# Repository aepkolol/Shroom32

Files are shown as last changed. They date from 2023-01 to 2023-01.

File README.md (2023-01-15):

# Shroom32
mycology monitoring and automation

This is the start of a project to monitor and automate a "fuiting" tub for growing mushrooms. 

I'll give some basic building instructions, but at the moment this is a very rough project I started a few days ago from parts I already had on hand. I included the fusion360 file I was buildig this in for others to edit to suit their needs if needed. Some details may be missing/lacking. Feel free to open an issue and I can clarify anything. This was also my first time using the water level sensor, it came in a kit of other parts years ago. My initial tests show it sucks. I don't feel like fixing that right now, so feel free to omit it, the code should run fine without, it'll just constantly show 0% water. 

Right now the water chamber is filled via a mountain dew bottle with a hole drilled into the cap where the water tube goes. I'll eventually make something nicer. The idea is to have water gravity fed via that tube and it should stop at the right water level as long as the tube is secured properly inside. 

The webapp is also pretty rough at the moment while I add features to it. Its designed with Bootstrap5 and uses websockets to talk to the "server" to get sensor data. The data is graphed using charts.js. 

The humidity is controlled by an ultrasonic mister bought off Amazon and a 5010 radial fan partially disasembled. (I may have stole this idea from the Voron 3D printer team). The monitoring is done mainly by a BME688 sensor. 
Right now the main webpage displays the humidity, temperature, pressure and gas as a KOhm value. 
It is possible to use the AI gas detection of the BME688 sensor, however I'm not entirely sure how to go about that. If someone smarter than me wants to figure that out, please do. Maybe a graph of CO2 in the fruiting chamber? Detection of unwanted bacteria growth? I dunno! It's over my head at the moment. 

## TODO:
- Store x amount of sensor values serverside to save graph data between browser refreshes
- Edit and save batch info/dates.
- Save min/max values to the SPIFFs 
- Add neopixel lighting to the inside of the fruiting chamber with adjustable time cycles
- Some way to notify user of an alarm state (temp/humidity/water, etc)
- Ability to have more than one, and link the data to a central node
- Design a gravity fed water supply to the humidifier. 
- Possibly slight redesigns to use an ESP32 cam module for real time viewing inside the fruiting chamber. 

## Parts required:
- The contents of the "STL" folder 3D printed in the material of your choice (PETG prefered, a soft TPE for the gaskets)
- a 24v 5010 radial fan (TBD: Add link to exact one)
- a ultrasonic mister (TBD: Add link to exact one)
- BME688
- Water sensor (TBD: Add link to exact one)
- ESP32
- Relay module
- Buck converter
- Potentiometer (if you want fan control) <- Not the best way to do this, but how I'm doing it for now.
- 4x M3 heatset inserts
- Countersunk M3 and M2.5 screws
- A few feet of 6.5mm OD silicone tube. I had some on hand from some random Amazon DC pumps. 

## Pinouts 
You can wire this how you choose to, the pins are defined in the start of main.cpp. This is how it is default. 
- BME688
  - SDA - GPIO_21
  - SCL - GPIO_22
  - GND - GND
  - VCC - 3.3v/5v depending on sensor
  
- Relay 
  - COM - 12v in
  - NO - V+ to Ultrasonic mister and potentometer
  - NC - Not connected 
  - VCC - 5v from buck converter
  - GND - out neg from buck
  - TRIG - GPIO_16
  
- Water sensor 
  - VCC - GPIO_27
  - GND - GND of ESP32 or buck converter 
  - SENSE - GPIO_34
  
- Fan
  - V+ - Output of potentiometer
  - V- - neg of 12v input (I soldered to the IN side of the buck)
  
## Printing:
- Gaskets - Use a soft TPE material. If you don't have the ability to print TPE, you can probably use hot glue or RTV or something. You may need to edit the CAD files to adjust the fit of the bottom lid since it takes into account the gaskets. 
- Everything else - PETG is probably best. You do you though. 

## Building:
See the guide folder for basic building instructions

## Issues:
- 24v radial fan is too powerful IMO. My quick fix was to add a potentiometer to limit the voltage of the fan. This works, but isn't ideal. Since the fan isn't on 100% of the time, it should be fine. If the fan draws too much power or shorts out, it could burn out the pot. 
- Water level sensor sucks. 
- I haven't designed a mount for the BME688 sensor, mine is just hanging by the wires while I worked on the rest of the stuff.

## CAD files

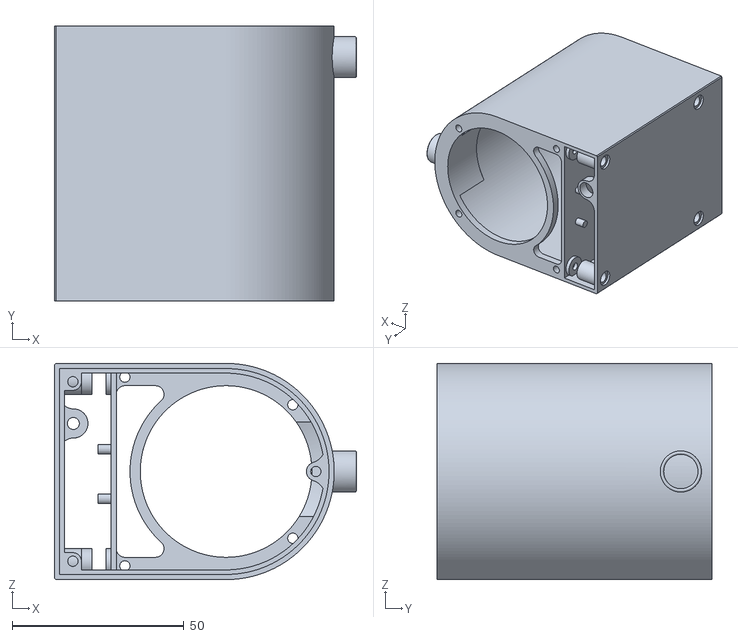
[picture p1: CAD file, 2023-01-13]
STL/Main Body.stl
88.0 x 80.0 x 63.0

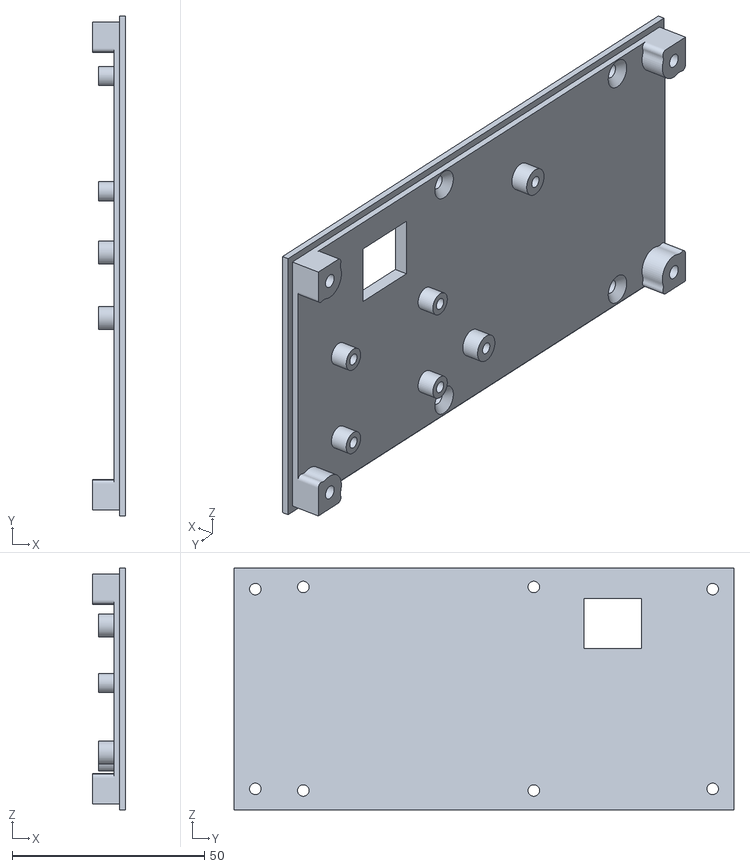
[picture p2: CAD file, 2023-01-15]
STL/Outside box.stl
8.50 x 130.1 x 63.0

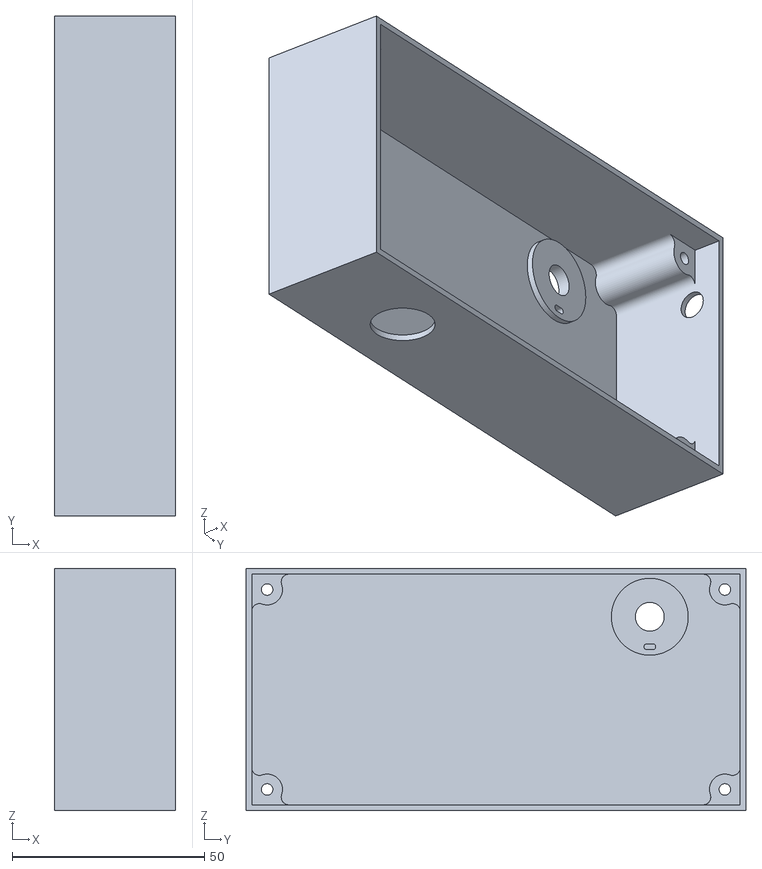
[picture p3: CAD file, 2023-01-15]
STL/Outside cover.stl
31.5 x 130.1 x 63.0

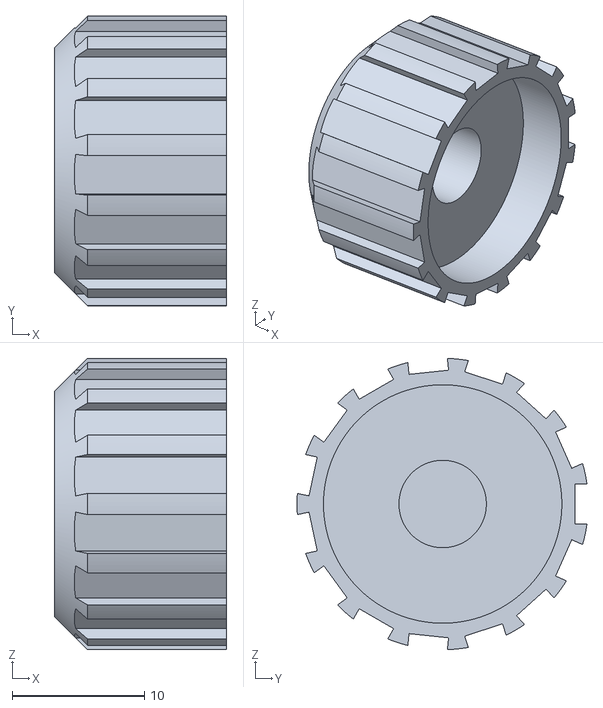
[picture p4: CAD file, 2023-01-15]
STL/Knob.stl
13.0 x 21.9 x 22.0

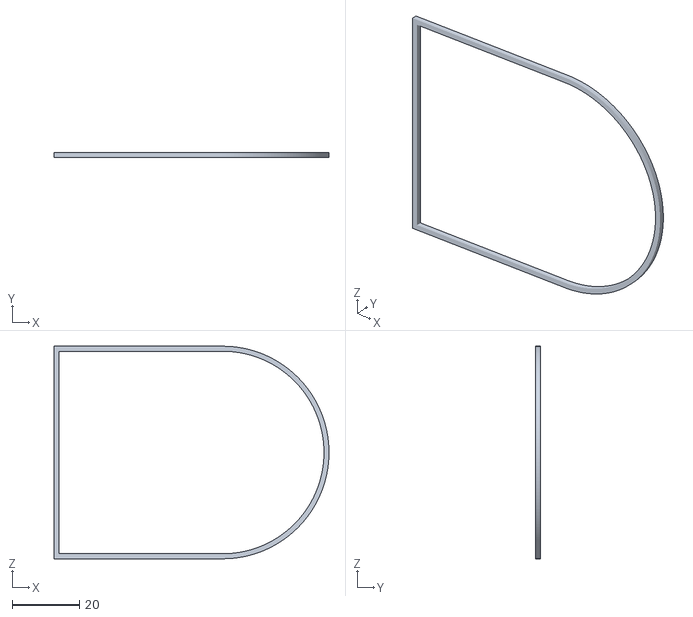
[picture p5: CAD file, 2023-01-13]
STL/Gasket.stl
81.5 x 1.40 x 63.0

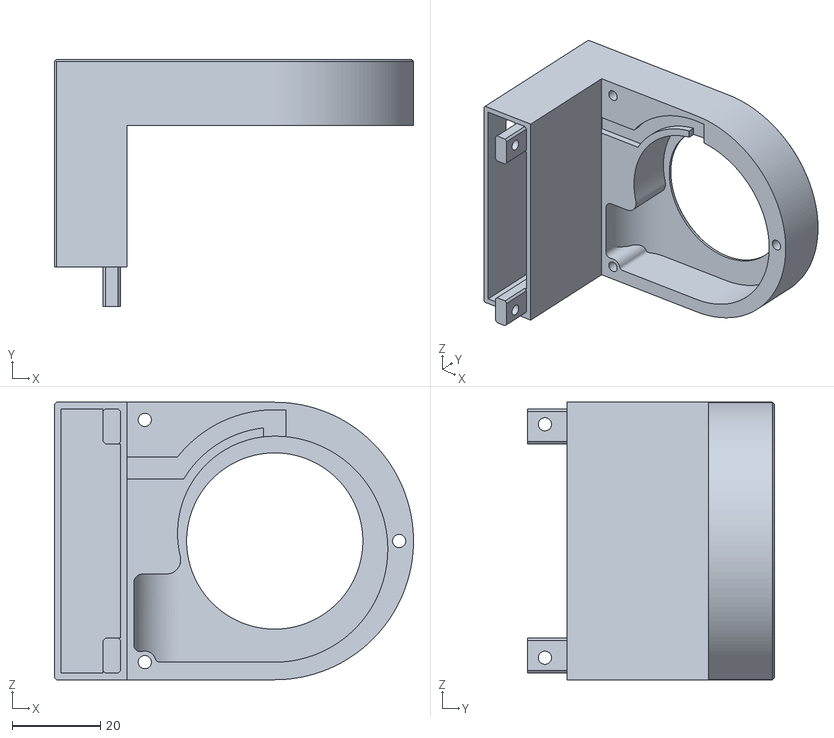
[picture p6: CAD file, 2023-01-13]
STL/Fan shroud.stl
81.5 x 56.0 x 63.0

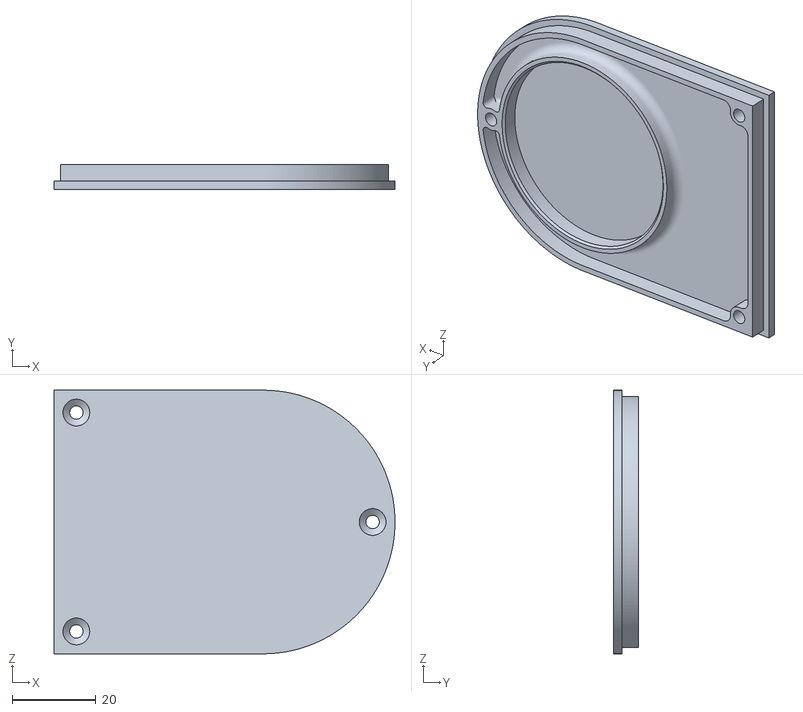
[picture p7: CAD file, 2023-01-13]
STL/Bottom.stl
81.5 x 6.00 x 63.0

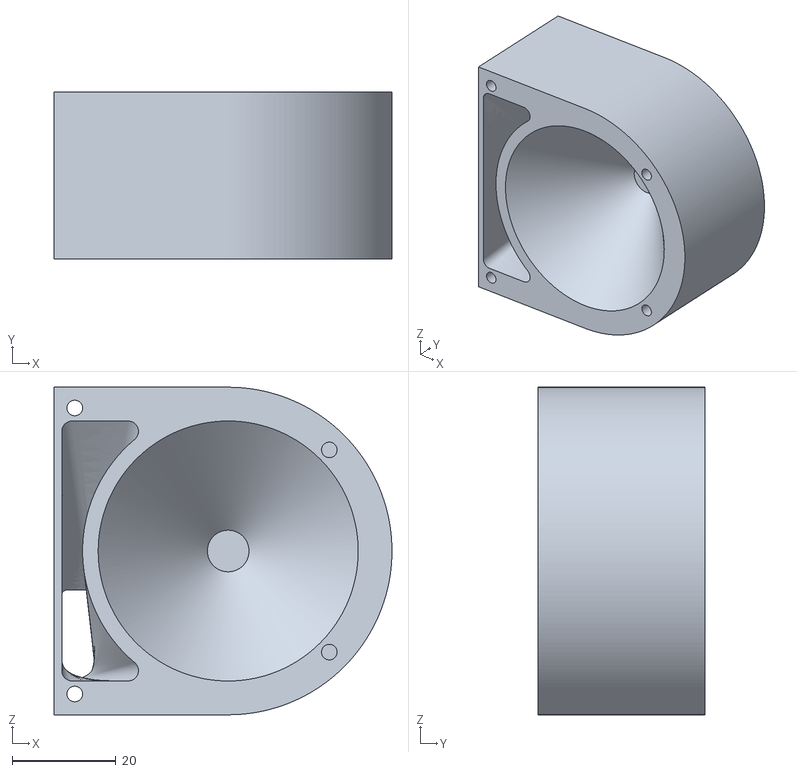
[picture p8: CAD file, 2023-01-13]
STL/Drip catch.stl
65.0 x 32.1 x 63.0

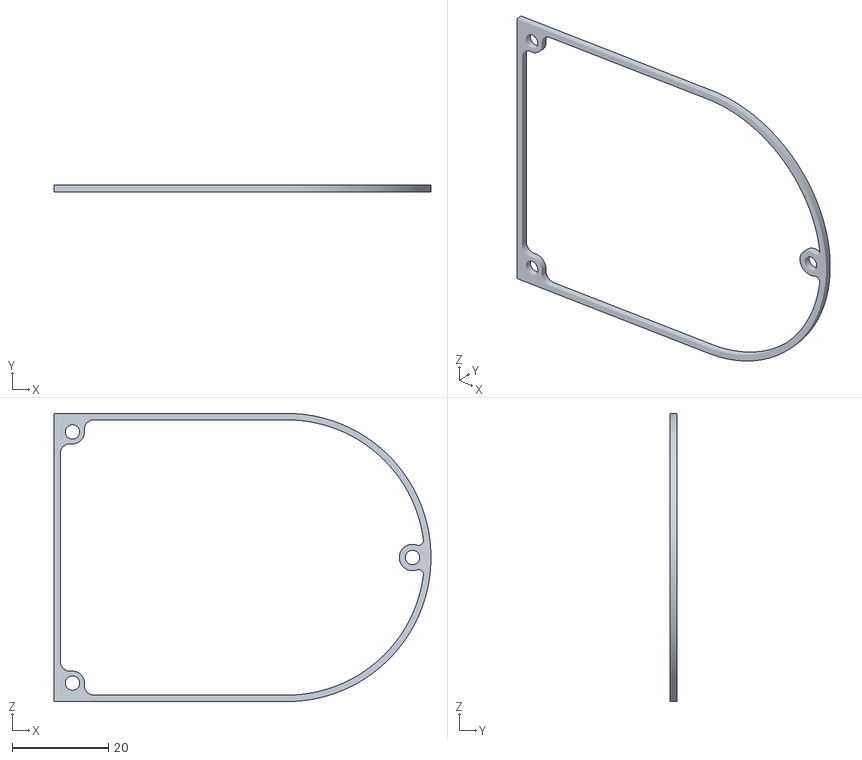
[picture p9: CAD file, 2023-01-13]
STL/Inner Gasket.stl
78.5 x 1.40 x 60.0

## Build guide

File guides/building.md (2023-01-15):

## The fan shroud 

This is the part that actually blows the humidified air out of the main body. To start, you'll need a 5015 radial fan. Remove the top casing from the fan by breaking off the tabs. You'll also need to remove the "ears". I used wire cutters to snip the casing beside the ears and bent them off. You can be pretty messy with this, it's going inside another enclosure. It just needs to fit, and the fan blades need to spin freely. 

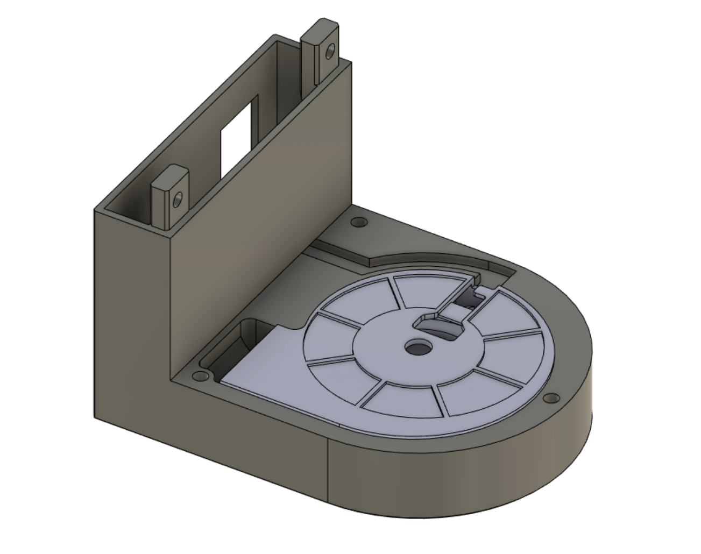
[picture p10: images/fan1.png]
guide image


Now place this modified fan inside the fanshroud.stl you printed off. Fit the wiring of the fan in the wire path and through the hole at the end of the path. 

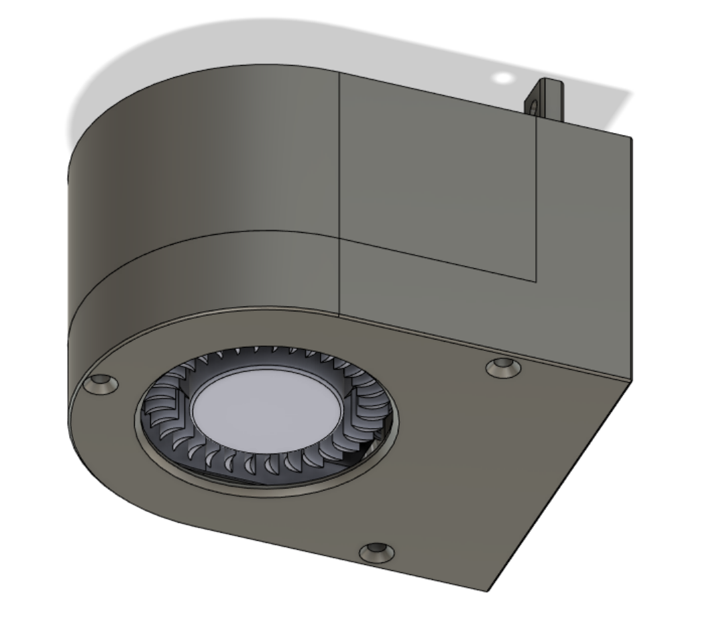
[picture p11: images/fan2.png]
guide image


Now you can screw the "dripcatch.stl" to the fan shroud using 3x countersunk M3 screws. 

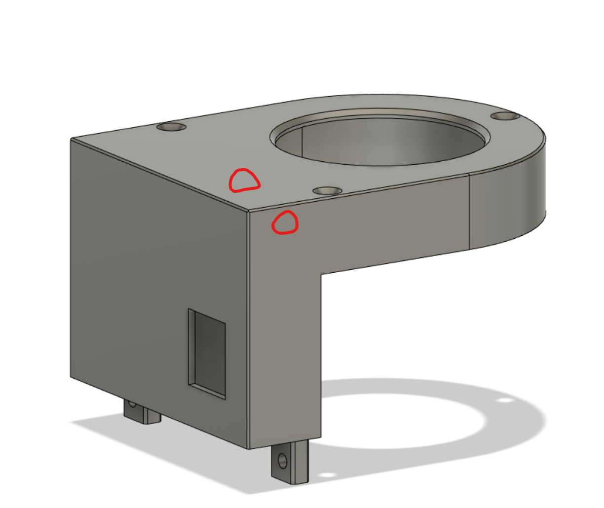
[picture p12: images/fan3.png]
guide image


Drill a hole in the highlighted spots on the fanshroud.stl. This is where the wiring for the BME688 (And possibly the neopixels later) will exit the body. Where the holes are is really up to you and how you want the sensor positioned. 

## The main body

Insert 4x M3 heated inserts into the 4 holes on the back of the main body using a soldering iron. If you haven't done this before, read a guide on 3D printed heating inserts before attempting this. 

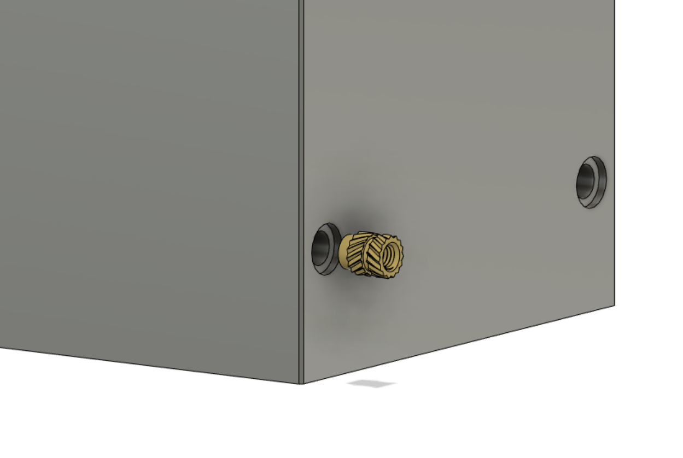
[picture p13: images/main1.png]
guide image


Solder/attach your V+, GND and SENSE wires to the waterlevel sensor if you're using it. Then use some double sided foam tape, or hot glue to mount it to the mounting point inside the main body. 

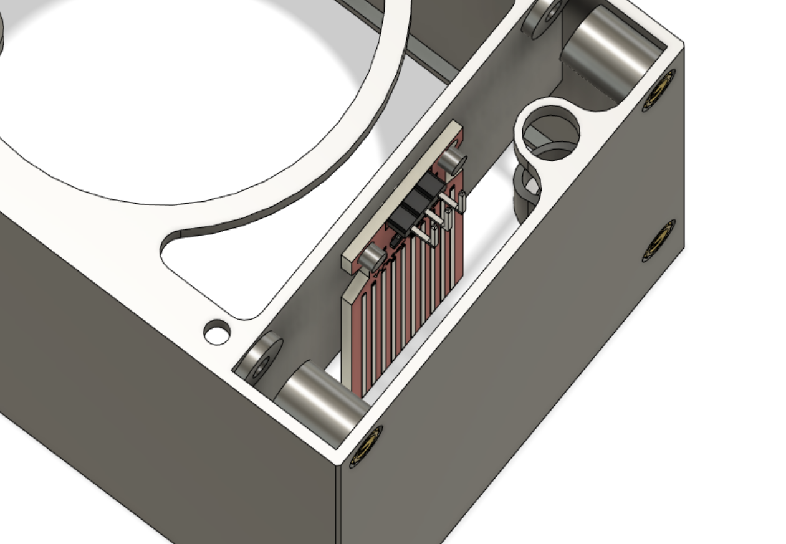
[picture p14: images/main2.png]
guide image


Add a length of 6.5mm silicone tubing inside the main body in the spots provided. 1 - 1.5ft is probably more than enough. 

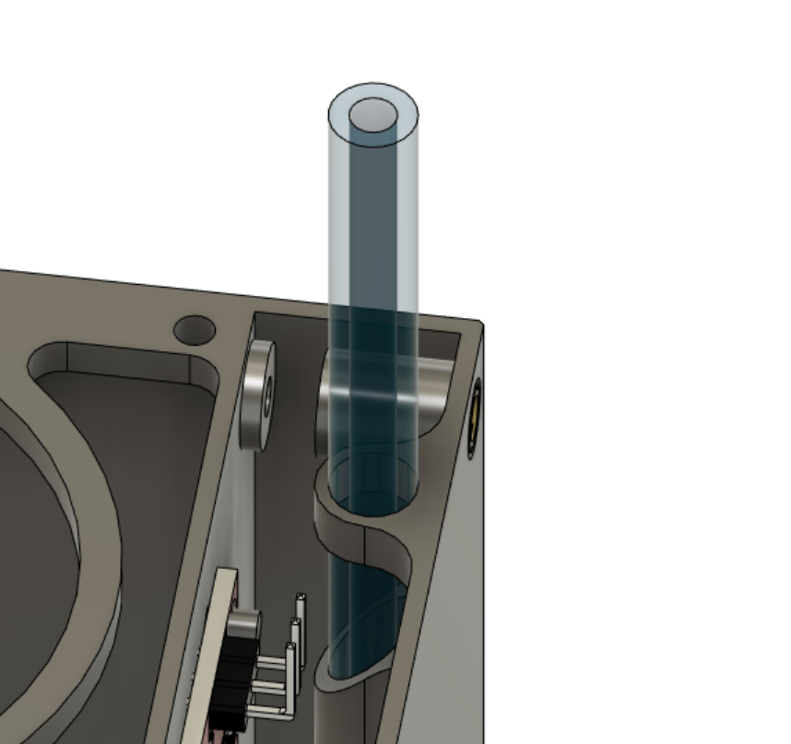
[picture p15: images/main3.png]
guide image


Feed the wires from the water sensor and fan through the exit hole in the main body. Now use 4x M3 screws to secure it to the "dripcatch.stl"

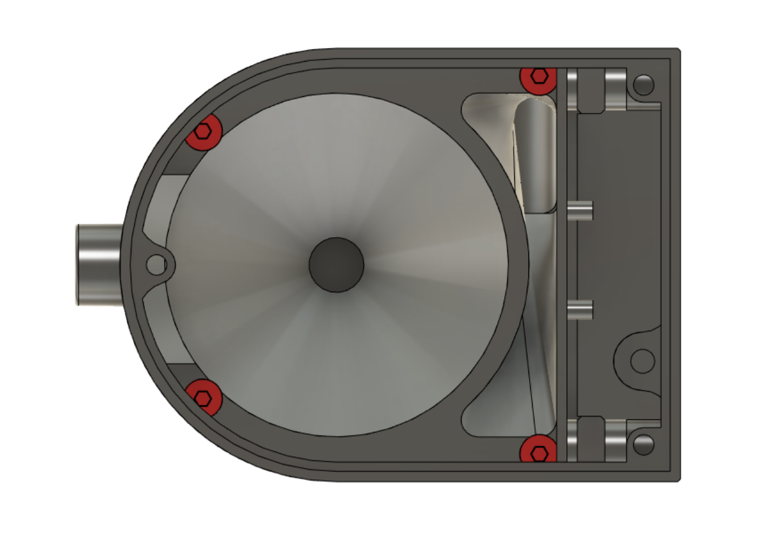
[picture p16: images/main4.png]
guide image


Add the TPE gaskets to the bottom lid of the main body. Apply a thick coating of silicone grease along the gasket to help seal the main body and keep it water tight. I found it helped thread the screws into the bottom to hold the gasket in place while you install the bottom lid.

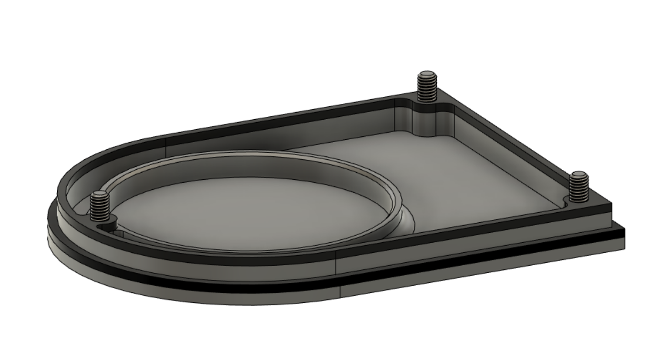
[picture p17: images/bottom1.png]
guide image


Place the ultrasonic mister into the bottom lid, and run the wires through the main body past the water sensor and out the same hole as the rest of the wiring.

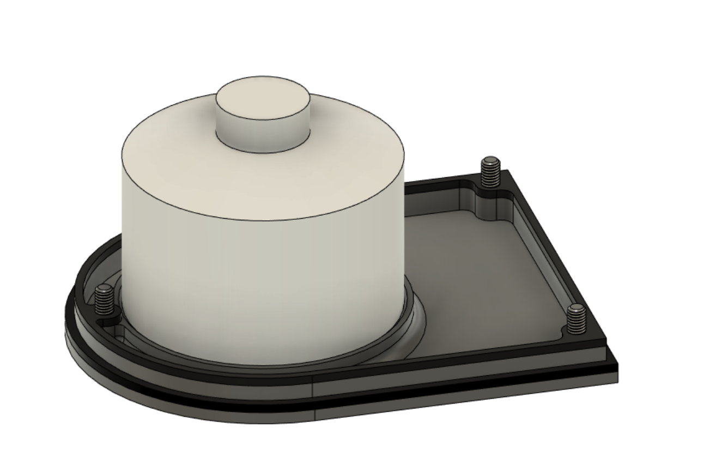
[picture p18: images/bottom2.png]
guide image


Now screw the bottom to the main body.

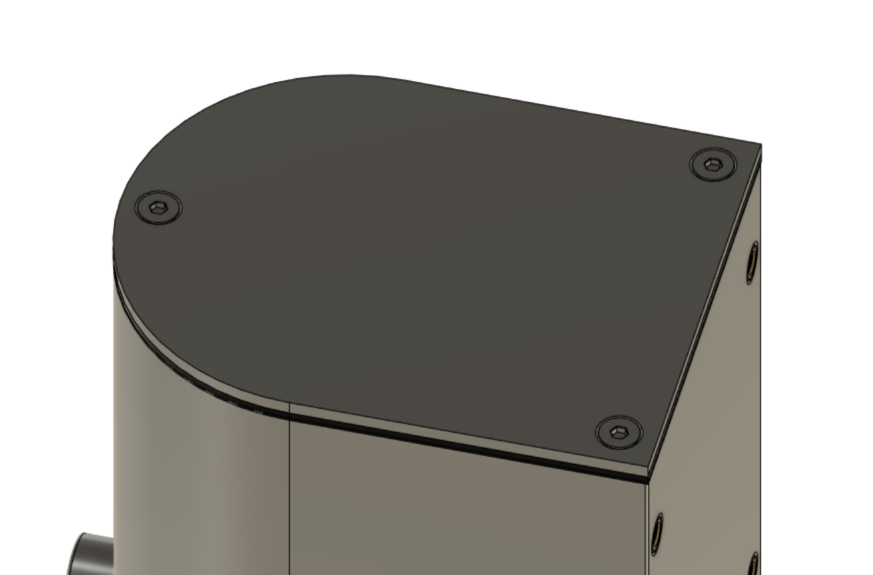
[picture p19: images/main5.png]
guide image


## Outside the tub

Place the "outsidebox.stl" in the position you want it to be installed on the fruiting tub. Use a 3mm drill bit to drill 4 holes through the tub where the mounting screws will pass through. Use a bigger bit, series of small holes, a dremel, etc to cut the square hole where the wires and water tube will pass through the box. 

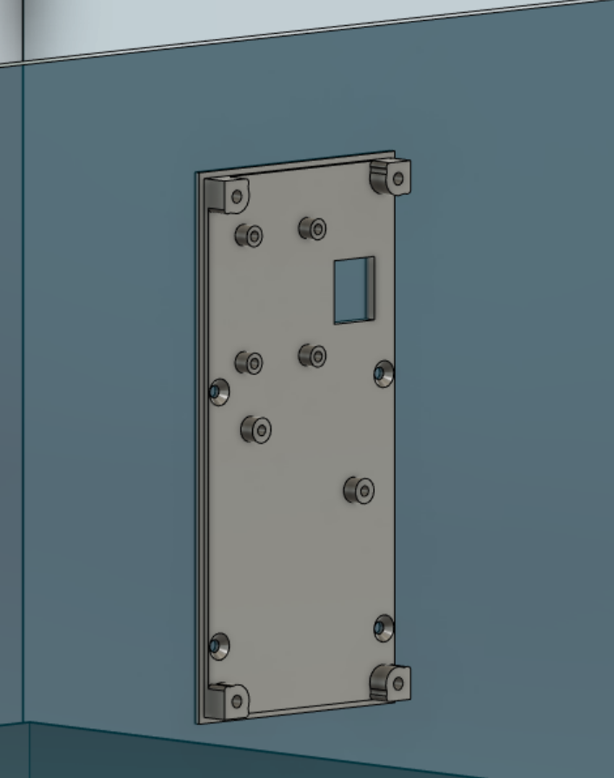
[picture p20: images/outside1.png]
guide image


Use 4x M3 countersunk screws to mount the shroom32 to the fruiting tub

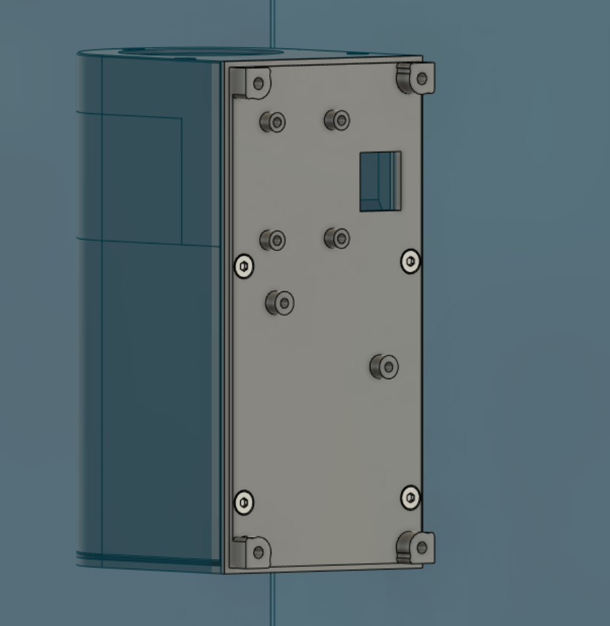
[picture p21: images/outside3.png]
guide image


Use M2.5 screws to secure the relay and DC buck to the body. 

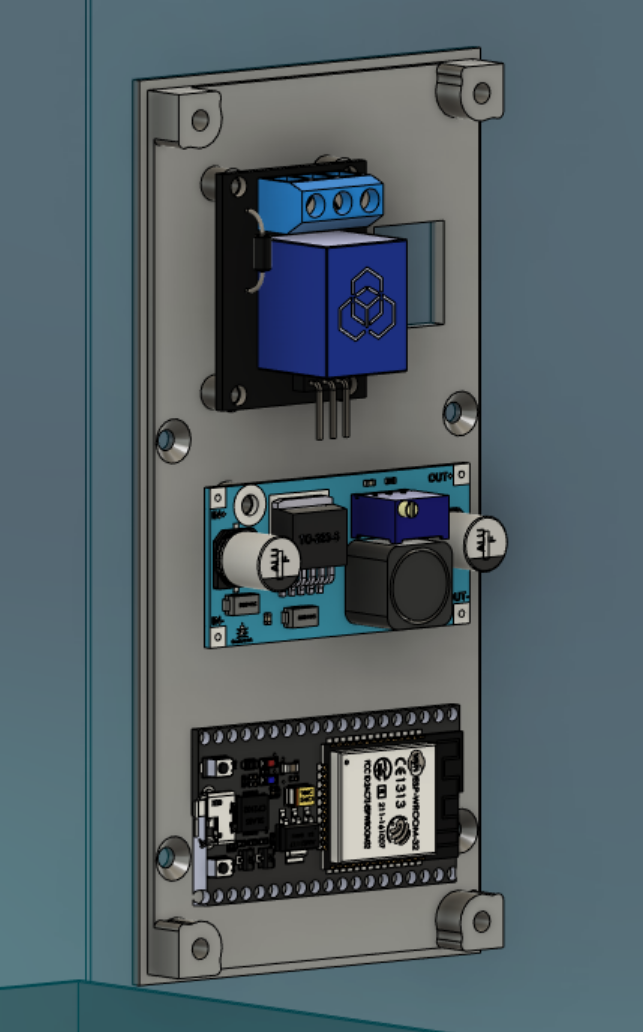
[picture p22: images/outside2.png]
guide image


Attach the potentiometer to the outside box cover. Now is a good time to also solder the 3 wires to the legs.

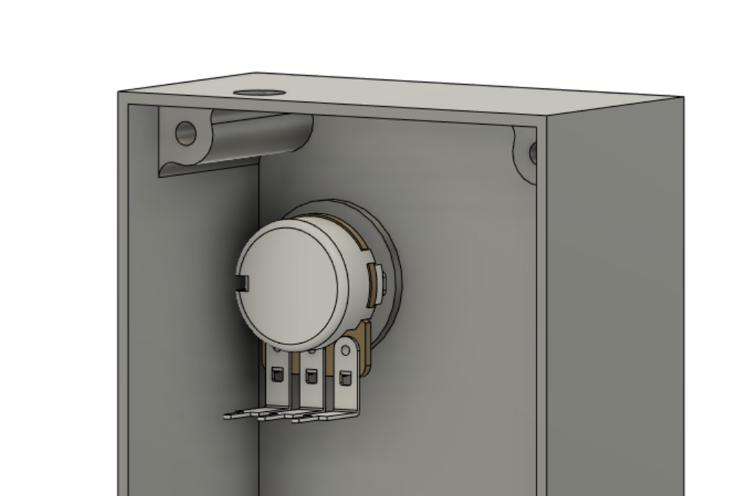
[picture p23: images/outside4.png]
guide image


Start wiring! 

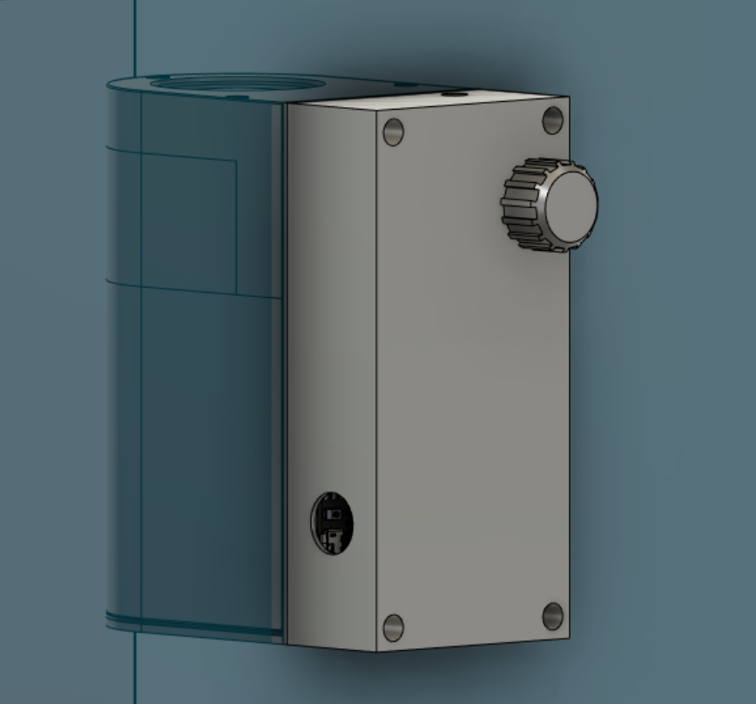
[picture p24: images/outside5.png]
guide image


Close everything up with the box cover. You can pass the water tube though the hole in the top and the DC input wires through the hole in the side.

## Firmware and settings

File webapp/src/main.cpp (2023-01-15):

#include <Arduino.h>
#include <Wire.h>
#include <WiFi.h>
#include <AsyncTCP.h>
#include <ESPAsyncWebServer.h>
#include <Arduino_JSON.h>
#include "SPIFFS.h"
#include <Adafruit_Sensor.h>
#include "Adafruit_BME680.h"

// Replace with your network credentials
const char *ssid = "KingStan";
const char *password = "ST4NL333";

// setup mister/fan relay
const int misterRelay = 16;

// Setup delays
unsigned long lastTime = 0;
unsigned long lastTimeChart = 0;
unsigned long lastTimeSensor = 0;
unsigned long sensorDelay = 1000;
unsigned long chartDelay = 30000;

// BME680 Sensor
#define SEALEVELPRESSURE_HPA (1013.25) // Change this to your local sea level pressure in hPa if you want to calculate altitude
Adafruit_BME680 bme; // I2C

// Water level sensor
int waterLevelMin = 0;  // This is the raw value of the sensor when the water is at the bottom of the tank
int waterLevelMax = 150; // This is the raw value of the sensor when the water is at the top of the tank

const int waterLevelInput = 34;
const int waterLevelOutput = 27;
int b1WaterLevelRaw = 0;
int b1WaterLevel = 0;

// Create AsyncWebServer object on port 80
AsyncWebServer server(80);

// Create an Event Source on /events
AsyncEventSource events("/events");

// Box 1 Sensor Data
float b1Temp = 0;
float b1Humidity = 0;
float b1Pressure = 0;
float b1Gas = 0;
float b1TempMin = 0;
float b1TempMax = 0;
float b1HumidityMin = 0;
float b1HumidityMax = 0;
float b1PressureMin = 0;
float b1PressureMax = 0;
float b1GasMin = 0;
float b1GasMax = 0;

JSONVar b1SensorDoc;
String b1SensorString;

JSONVar b1StatusDoc;
String b1StatusString;

int checkWater() { // This water level sensor sucks, may just change it out for a float switch
  int level1 = 0;
  int level2 = 0;
  int level3 = 0;

  digitalWrite(waterLevelOutput, HIGH); // Turn on the water sensor
  delay(1000); // Wait for the sensor to settle
  level1 = analogRead(waterLevelInput); // Read the water sensor
  delay(100);
  level2 = analogRead(waterLevelInput); // Read the water sensor
  delay(100);
  level3 = analogRead(waterLevelInput); // Read the water sensor
  b1WaterLevelRaw = (level1 + level2 + level3) / 3; // Average the readings
  digitalWrite(waterLevelOutput, LOW); // Turn off the water sensor
  b1WaterLevel = map(b1WaterLevelRaw, waterLevelMin, waterLevelMax, 0, 100); // Map the raw value to a percentage
  return b1WaterLevel;
}

String sendB1Sensors()
{
  // Tell BME680 to begin measurement.
  unsigned long endTime = bme.beginReading();
  if (endTime == 0)
  {
    Serial.println(F("Failed to begin reading :("));
    return "Failed to begin reading";
  }

  if (!bme.endReading())
  {
    Serial.println(F("Failed to complete reading :("));
    return "Failed to complete reading";
  }

  b1Temp = bme.temperature;            // in degrees Celsius (the default)
  b1Humidity = bme.humidity;           // in % relative humidity (the default)
  b1Pressure = bme.pressure / 100.0;   // in hectopascals (hPa)
  b1Gas = bme.gas_resistance / 1000.0; // in KOhms

  b1SensorDoc["b1Temp"] = b1Temp;
  b1SensorDoc["b1Humidity"] = b1Humidity;
  b1SensorDoc["b1Pressure"] = b1Pressure;
  b1SensorDoc["b1Gas"] = b1Gas;

  if (b1TempMin == 0 || b1TempMin > b1Temp)
  {
    b1TempMin = b1Temp;
  }

  if (b1TempMax == 0 || b1TempMax < b1Temp)
  {
    b1TempMax = b1Temp;
  }

  if (b1HumidityMin == 0 || b1HumidityMin > b1Humidity)
  {
    b1HumidityMin = b1Humidity;
  }

  if (b1HumidityMax == 0 || b1HumidityMax < b1Humidity)
  {
    b1HumidityMax = b1Humidity;
  }

  if (b1PressureMin == 0 || b1PressureMin > b1Pressure)
  {
    b1PressureMin = b1Pressure;
  }

  if (b1PressureMax == 0 || b1PressureMax < b1Pressure)
  {
    b1PressureMax = b1Pressure;
  }

  if (b1GasMin == 0 || b1GasMin > b1Gas)
  {
    b1GasMin = b1Gas;
  }

  if (b1GasMax == 0 || b1GasMax < b1Gas)
  {
    b1GasMax = b1Gas;
  }

  b1SensorDoc["b1TempMin"] = b1TempMin;
  b1SensorDoc["b1TempMax"] = b1TempMax;
  b1SensorDoc["b1HumidityMin"] = b1HumidityMin;
  b1SensorDoc["b1HumidityMax"] = b1HumidityMax;
  b1SensorDoc["b1PressureMin"] = b1PressureMin;
  b1SensorDoc["b1PressureMax"] = b1PressureMax;
  b1SensorDoc["b1GasMin"] = b1GasMin;
  b1SensorDoc["b1GasMax"] = b1GasMax;
  b1SensorDoc["b1WaterLevel"] = checkWater();

  b1SensorString = JSON.stringify(b1SensorDoc);
  Serial.println(b1WaterLevelRaw);
  return b1SensorString;
}

void initSPIFFS()
{
  if (!SPIFFS.begin())
  {
    Serial.println("An error has occurred while mounting SPIFFS");
  }
  Serial.println("SPIFFS mounted successfully");
}

// Initialize WiFi
void initWiFi()
{
  WiFi.mode(WIFI_STA);
  WiFi.begin(ssid, password);
  Serial.println("");
  Serial.print("Connecting to WiFi...");
  while (WiFi.status() != WL_CONNECTED)
  {
    Serial.print(".");
    delay(1000);
  }
  Serial.println("");
  Serial.println(WiFi.localIP());
}

void initBME680()
{
  while (!Serial)
    ;
  Serial.println(F("BME680 async test"));

  if (!bme.begin(0x76))
  {
    Serial.println(F("Could not find a valid BME680 sensor, check wiring!"));
    while (1)
      ;
  }

  // Set up oversampling and filter initialization
  bme.setTemperatureOversampling(BME680_OS_8X);
  bme.setHumidityOversampling(BME680_OS_2X);
  bme.setPressureOversampling(BME680_OS_4X);
  bme.setIIRFilterSize(BME680_FILTER_SIZE_3);
  bme.setGasHeater(320, 150); // 320*C for 150 ms
}



void turnMisterOn()
{
  digitalWrite(misterRelay, HIGH);
  b1StatusDoc["mister"] = "ON";
  b1StatusString = JSON.stringify(b1StatusDoc);
  events.send(b1StatusString.c_str(), "Box1_Status", millis());
}

void turnMisterOff()
{
  digitalWrite(misterRelay, LOW);
  b1StatusDoc["mister"] = "OFF";
  b1StatusString = JSON.stringify(b1StatusDoc);
  events.send(b1StatusString.c_str(), "Box1_Status", millis());
}

void setup()
{
  Serial.begin(115200);
  // Wire.begin(SDA, SCL);
  initWiFi();
  initSPIFFS();
  initBME680();
  pinMode(misterRelay, OUTPUT); // Set the mister relay pin as an output
  pinMode(waterLevelOutput, OUTPUT); // Set the water level output pin as an output
  pinMode(waterLevelInput, INPUT); // Set the water level input pin as an input
  digitalWrite(waterLevelOutput, LOW); // Turn the water level sensor off, so it doesn't corrode fast

  // Handle Web Server
  server.on("/", HTTP_GET, [](AsyncWebServerRequest *request)
            { request->send(SPIFFS, "/index.html", "text/html"); });

  server.serveStatic("/", SPIFFS, "/");

  server.on("/mister/ON", HTTP_GET, [](AsyncWebServerRequest *request)
            {
    turnMisterOn();
    request->send(200, "text/plain", "OK"); });

  server.on("/mister/OFF", HTTP_GET, [](AsyncWebServerRequest *request)
            {
    turnMisterOff();
    request->send(200, "text/plain", "OK"); });

  // Handle Web Server Events
  events.onConnect([](AsyncEventSourceClient *client)
                   {
    if(client->lastId()){
      Serial.printf("Client reconnected! Last message ID that it got is: %u\n", client->lastId());
    }
    // send event with message "hello!", id current millis
    // and set reconnect delay to 1 second
    client->send("hello!", NULL, millis(), 10000); });
  server.addHandler(&events);

  server.begin();
}

void loop()
{
  if ((millis() - lastTime) > sensorDelay)
  {
    // Send Events to the Web Server with the Sensor Readings
    events.send(sendB1Sensors().c_str(), "Box1_Sensors", millis());
    lastTime = millis();
  }
  if ((millis() - lastTimeChart) > chartDelay)
  {
    // Send Events to the Web Server with the Sensor Readings
    events.send(sendB1Sensors().c_str(), "Box1_Chart", millis());
    lastTimeChart = millis();
  }
}
